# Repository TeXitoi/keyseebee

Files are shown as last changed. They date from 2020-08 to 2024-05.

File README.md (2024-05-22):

# KeySeeBee

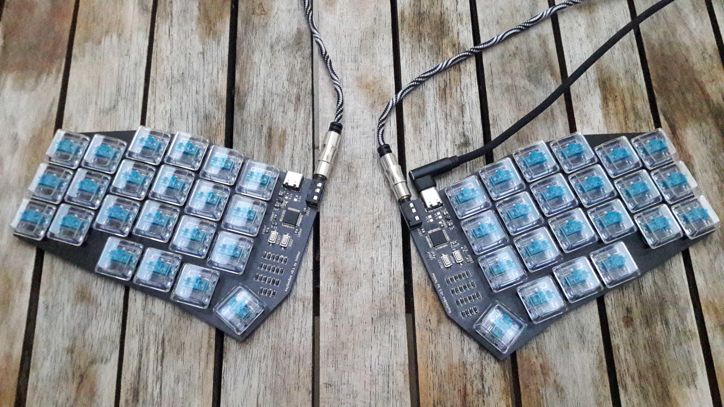
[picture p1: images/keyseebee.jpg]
KeySeeBee


KeySeeBee is a split ergo keyboard. It is only 2 PCB (so the name)
with (almost) only SMD components on it. It's only a keyboard, no LED,
no display, nothing more than keys and USB.

The firmware is [Keyberon](https://github.com/TeXitoi/keyberon), a
pure rust firmware.

## Features

 * 44 keys, using Cherry MX or Kailh choc switches, only 1U keycaps.
 * USB-C connector on the 2 sides.
 * TRRS cable for connecting the 2 halves (for power and UART communication between the 2 halves).
 * 2 STM32F072 MCU, with hardware USB DFU bootloader and crystal less USB;
 * Only onboard SMD component (except for the switches and TRRS
   connector).
 * [Plate files](cad/) (optional).

## Inspiration

 * [Plaid](https://github.com/hsgw/plaid) for "show the components"
 * [GergoPlex](https://www.gboards.ca/product/gergoplex) for "just a keyboard" and "only a PCB with SMD components"
 * [Lily58](https://github.com/kata0510/Lily58) for the thumb cluster
 * [Kyria](https://blog.splitkb.com/blog/introducing-the-kyria) for
   "don't be affraid of pinky stagger"

## Gallery

### v0.1, build by TeXitoi

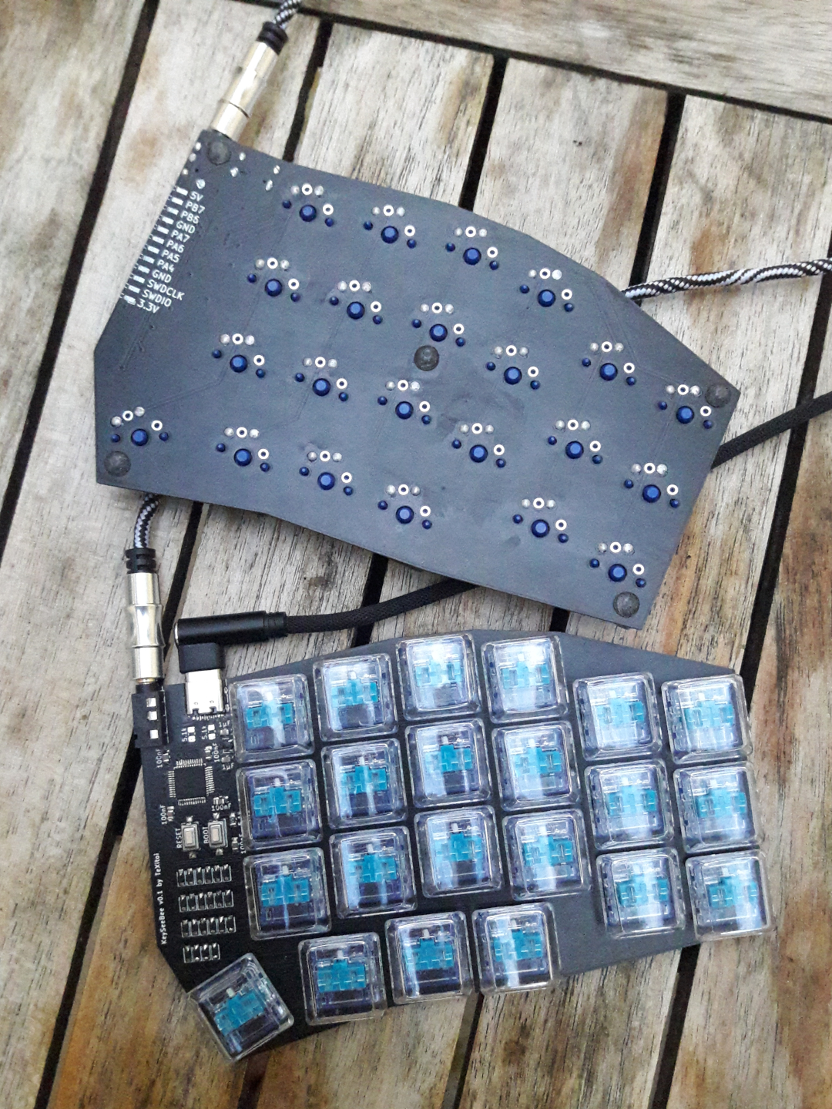
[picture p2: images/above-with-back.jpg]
From above with one side upside down


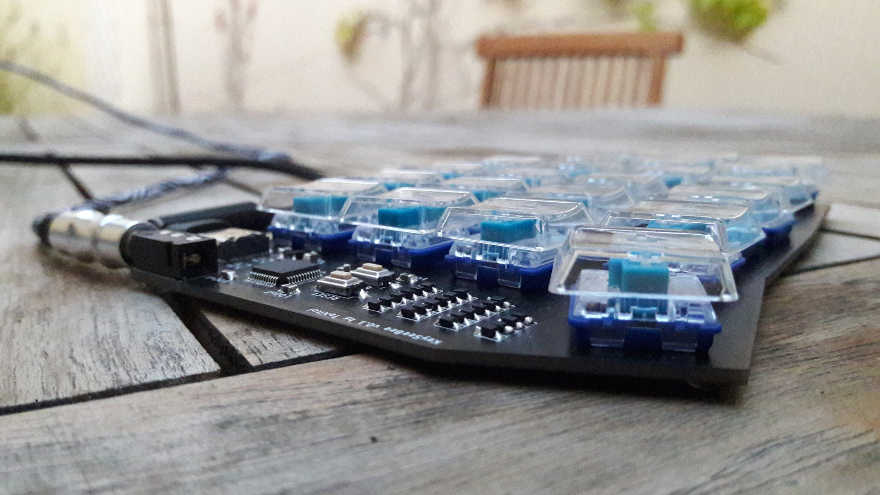
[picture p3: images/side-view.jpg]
Side view


### v0.1, build by TeXitoi, Gateron silent clear (MX footprint), 3D printed plate

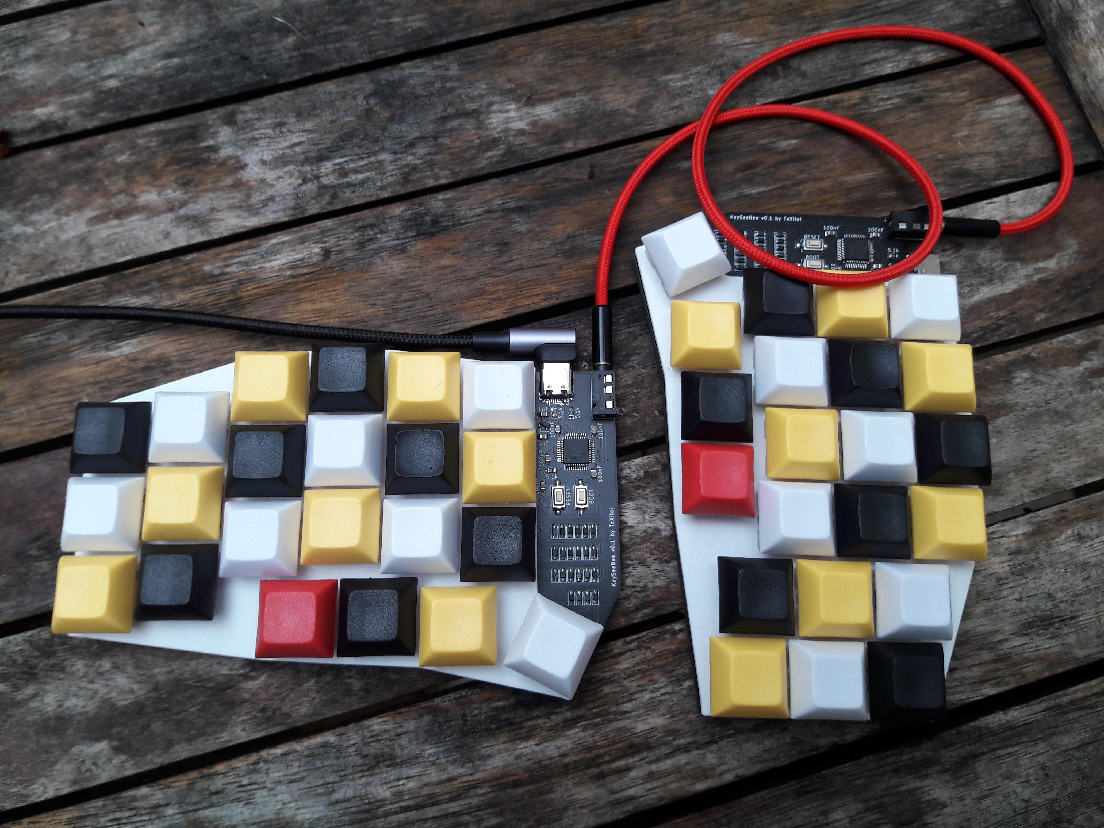
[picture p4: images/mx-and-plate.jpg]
From above


### v0.2, build by eropleco, with 1.2mm anodized aluminium plate

Left

Right

### v0.3, build by TeXitoi, Gateron silent clear, 3D printed fat plate

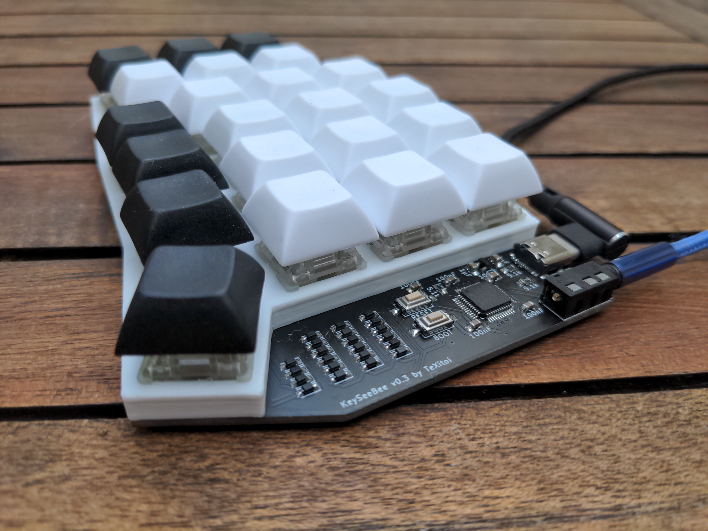
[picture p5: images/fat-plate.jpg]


## Bill Of Materials

Price is for 5 keyboards including shipping.

|Item |Package|Qty|Remarks |Price |
|---|---|--:|---|-----:|
|[Left PCB](pcb/gerbers/) | |  1|Ordered at [JLCPCB](https://jlcpcb.com)| |
|[Right PCB](pcb/gerbers/) | |  1|Ordered at [JLCPCB](https://jlcpcb.com)|33.14€|
|[USB-C connector](https://www.aliexpress.com/item/33004501788.html) |16 pins|  2| | 1.44€|
|[1N4148WS](https://www.aliexpress.com/item/32774043752.html) |SOD-323| 44|Price is for 1000 | 2.82€|
|[PJ320A TRRS connector](https://www.aliexpress.com/item/4000661212458.html)| |  2| | 1.01€|
|[STM32F072CBT6 MCU](https://www.aliexpress.com/item/1005002841528809.html)|LQFP-48|  2|STM32F072C8T6 would also work | 9.65€|
|[XC6206P332MR regulator](https://www.aliexpress.com/item/33015891307.html)|SOT-23 |  2|Price is for 50 | 1.93€|
|[SMD switch](https://www.aliexpress.com/item/4000546059630.html) | 3×6mm |  4|Price is for 100 | 1.35€|
|[5.1kΩ resistor](https://www.aliexpress.com/item/32865947306.html) | 0805  |  6|Price is for 100 | |
|[1µF capacitor](https://www.aliexpress.com/item/32964553793.html) | 0805  |  4|Price is for 100 | |
|[100nF capacitor](https://www.aliexpress.com/item/32964553793.html) | 0805  | 10|Price is for 100 | 3.46€|
|[Bumpers](https://www.aliexpress.com/item/32289191938.html) | 5×2mm | 10|Price is for 100 | 1.75€|
|[Cherry MX compatible](https://www.aliexpress.com/item/32836368723.html) or [Kailh Choc](https://www.aliexpress.com/item/1005005883472162.html) switch|5 pins (PCB mount)|44| | |
|1U keycap compatible with the chosen switches | | 44| | |
|[TRRS cable](https://www.aliexpress.com/item/1005003677396291.html) |Jack 3.5mm| 1|4 contacts needed | |
|[USB-C cable](https://www.aliexpress.com/item/1005002811739151.html) | |  1|USB-2 is enough | |

About 60€ without switches, keycaps and cables for 5 keyboards
(12€/keyboard).

## Compiling and flashing

Install the complete toolchain and utils:

```shell
curl https://sh.rustup.rs -sSf | sh
rustup target add thumbv6m-none-eabi
rustup component add llvm-tools-preview
cargo install cargo-binutils
sudo apt-get install dfu-util
```

Compile:

```shell
cd firmware
cargo objcopy --bin keyseebee --release -- -O binary keyseebee.bin
```

To flash using dfu-util, launch it with:
```shell
dfu-util -w -d 0483:df11 -a 0 -s 0x08000000:leave -D keyseebee.bin
```
Then, put the board in dfu mode by pressing BOOT, pressing and releasing
RESET and releasing BOOT. The upload should began as soon as the
computer detect the board in dfu mode.

The first time, if the write fail, your flash might be protected. To
unprotect:

```shell
dfu-util -d 0483:df11 -a 0 -s 0x08000000:force:unprotect -D keyseebee.bin
```

Ideally both sides needs to be flashed, but for changes that only affect the layout it's strictly not needed as the side connected with the USB cable will determine the layout. In fact, you can have different layouts stored on each half, meaning you can switch back and forth between two layouts by moving the USB cable between the two halves.

## What's the layout

Here is the [empty keyboard-layout-editor](http://www.keyboard-layout-editor.com/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) describing the layout.

I use the [ergol layout](https://ergol.org), so this is [the main layer](http://www.keyboard-layout-editor.com/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'%3B&@_y:-0.875&x:5%3B&=%0A%0A%0A%25%0A%0A%0AW&_x:5%3B&=%0A%0A%0A%2F@%0A%0A%0AJ%3B&@_y:-0.625&x:1%3B&=%0A%0A%C3%A2%0A%5E%0A%0A%0AQ&_x:13%3B&=%0A%0A%C3%BB%0A%60%0A%0A%0AY%3B&@_y:-0.8500000000000001&a:6%3B&=Tab&_x:15&a:4&f:3%3B&=%7B%0A%5B%3B&@_y:-0.7999999999999998&x:3&f:4%3B&=%0A%0A%C3%A8%0A%29%0A%0A%0AE&_x:9%3B&=%0A%0A%C3%AE%0A-%0A%0A%0AT%3B&@_y:-0.8500000000000001&x:2%3B&=%0A%0A%C3%A9%0A%28%0A%0A%0AS&_x:1%3B&=%0A%0A%C3%AA%0A%7D%0A%0A%0AN&_x:7%3B&=%0A%0A%29%0A+%0A%0A%0AR&_x:1%3B&=%0A%0A%C3%AF%0A%2F%2F%0A%0A%0AI%3B&@_y:-0.875&x:5%3B&=%0A%0A%C3%B1%0A%2F=%0A%0A%0AF&_x:5%3B&=%0A%0A%28%0A%5C%0A%0A%0AL%3B&@_y:-0.625&x:1%3B&=%0A%0A%C3%A0%0A%7B%0A%0A%0AA&_x:13%3B&=%0A%0A%C3%B9%0A%22%0A%0A%0AU%3B&@_y:-0.8500000000000001%3B&=%7D%0A%5D&_x:15&f:3%3B&=%22%0A'%3B&@_y:-0.7999999999999998&x:3&f:4%3B&=%3F%0A-%0A%E2%80%91%0A%5D&_x:9%3B&=%0A%0A%CE%B1%0A%2F%3B%0A%0A%0AG%3B&@_y:-0.8500000000000001&x:2%3B&=%0A%0A%C3%9F%0A%5B%0A%0A%0AX&_x:1%3B&=%0A%0A%E2%80%93%0A%2F_%0A%0A%0AV&_x:7%3B&=%0A%0A%0A!%0A%0A%0AH&_x:1%3B&=%2F%3B%0A,%0A%C2%B7%0A%2F:%3B&@_y:-0.875&x:5%3B&=%0A%0A%E2%80%94%0A%23%0A%0A%0AB&_x:5%3B&=%2F:%0A.%0A%E2%80%A6%0A%7C%3B&@_y:-0.625&x:1%3B&=%0A%0A%C3%A6%0A~%0A%0A%0AZ&_x:13%3B&=%0A%0A%C5%AD%0A%3F%0A%0A%0AK%3B&@_y:-0.8500000000000001%3B&=+%0A%2F=&_x:15&f:3%3B&=%7C%0A%5C%3B&@_y:-0.6500000000000004&x:2.5&a:6&f:4%3B&=GUI&_x:10%3B&=%E2%87%A7%20+%20AltGr%3B&@_rx:4&ry:8.175&y:-4.675000000000001&x:-0.5%3B&=Alt%3B&@_y:-0.875&x:0.5&a:0%3B&=nbsp%0A%E2%90%A3%0A%E2%80%99%0A%E2%90%A3%0Alayer%201%3B&@_rx:13&y:-4.675000000000001&x:-0.5&a:6%3B&=AltGr%3B&@_y:-0.875&x:-1.5&a:7%3B&=Layer%202%3B&@_r:30&rx:4&y:-4.825000000000001&x:-0.5&a:6&f:3%3B&=Ctrl%3B&@_r:-30&rx:13&y:-4.825000000000001&x:-0.5%3B&=%E2%87%A7) when I type.

The [layer 1](http://www.keyboard-layout-editor.com/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) is activated by holding `space`.

The [layer 2](http://www.keyboard-layout-editor.com/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,&_x:7%3B&=+&_x:1%3B&=%2F%2F%3B&@_y:-0.875&x:5%3B&=%2F=&_x:5%3B&=.%3B&@_y:-0.625&x:1%3B&=&_x:13%3B&=*%3B&@_y:-0.8500000000000001%3B&=&_x:15&f:3%3B&=%3B&@_y:-0.6499999999999999&x:2.5&a:6&f:4%3B&=GUI&_x:10&a:7%3B&=%3B&@_rx:4&ry:8.175&y:-4.675&x:-0.5&a:6%3B&=Alt%3B&@_y:-0.875&x:0.5&a:7%3B&=Ctrl+%E2%90%A3%3B&@_rx:13&y:-4.675&x:-0.5%3B&=AltGr%3B&@_y:-0.875&x:-1.5&g:true%3B&=%3B&@_r:30&rx:4&y:-4.825&x:-0.5&g:false&a:6&f:3%3B&=Ctrl%3B&@_r:-30&rx:13&y:-4.825&x:-0.5%3B&=%E2%87%A7) is activated by holding `Layer 2`.

The [layer 3](http://www.keyboard-layout-editor.com/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)
is activaded by holding `space` then `Layer 2`.

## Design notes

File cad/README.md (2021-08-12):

# Plate files

In version v0.1 and v0.2, the right thumb cluster is not at the exact
same place as the left one. It is corrected in v0.3 and after. If you
need a plate for pre-v0.3, look at the `is_right` option in the code.

You can find here some plates for the keyboard:
 * svg are seen from the top
 * stl are seen from the bottom, to have the visible side on the bed of a 3D printer.
 
The scad file is the source of these files. You can tune it to change,
for example, the swich hole size, depending on the tolerance you need.

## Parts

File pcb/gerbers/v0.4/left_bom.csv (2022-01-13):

Comment | Designator | Footprint | LCSC
100nF | C1,C2,C3,C4,C5 | Capacitor_SMD:C_0805_2012Metric_Pad1.15x1.40mm_HandSolder | C49678
1µF | C6,C7 | Capacitor_SMD:C_0805_2012Metric_Pad1.15x1.40mm_HandSolder | C28323
1N4148WS | D5,D6,D7,D9,D10,D11,D12,D14,D15,D16,D17,D19,D20,D21,D23,D24,D25,D26,D33,D34,D35,D36 | Diode_SMD:D_SOD-323_HandSoldering | C2128
USB_C_Receptacle_USB2.0 | J1 | kicad-usb:USB_C_Receptacle_HRO_TYPE-C-31-M-12 | C136423
AudioJack4 | J2 | keebio:TRRS-PJ-320A-no-Fmask
Conn_01x12_Male | J3 | kicad-harwin:Harwin_M20-89012xx_1x12_P2.54mm_Horizontal
5.1k | R1,R6,R7 | Resistor_SMD:R_0805_2012Metric_Pad1.15x1.40mm_HandSolder | C27834
BOOT | SW1 | Button_Switch_SMD:SW_SPST_CK_RS282G05A3 | C720381
RESET | SW2 | Button_Switch_SMD:SW_SPST_CK_RS282G05A3 | C720381
SW_Push | SW3,SW4,SW5,SW7,SW8,SW9,SW10,SW12,SW13,SW14,SW15,SW17,SW18,SW19,SW21,SW22,SW23,SW24,SW31,SW32,SW33,SW34 | custom:CherryMX_Choc_1u
STM32 | U1 | Package_QFP:LQFP-48_7x7mm_P0.5mm | C80488
LDO | U2 | Package_TO_SOT_SMD:SOT-23 | C5446

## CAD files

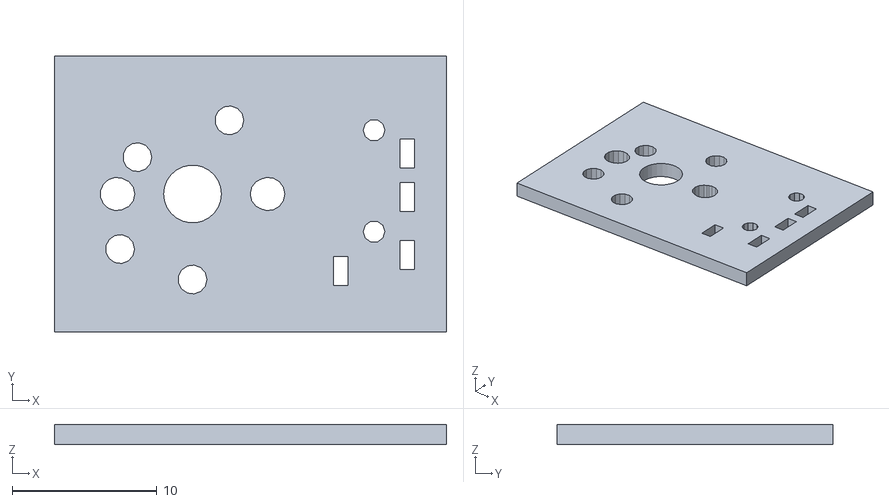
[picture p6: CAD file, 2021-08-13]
cad/cutting_pattern.stl
27.0 x 19.0 x 1.40

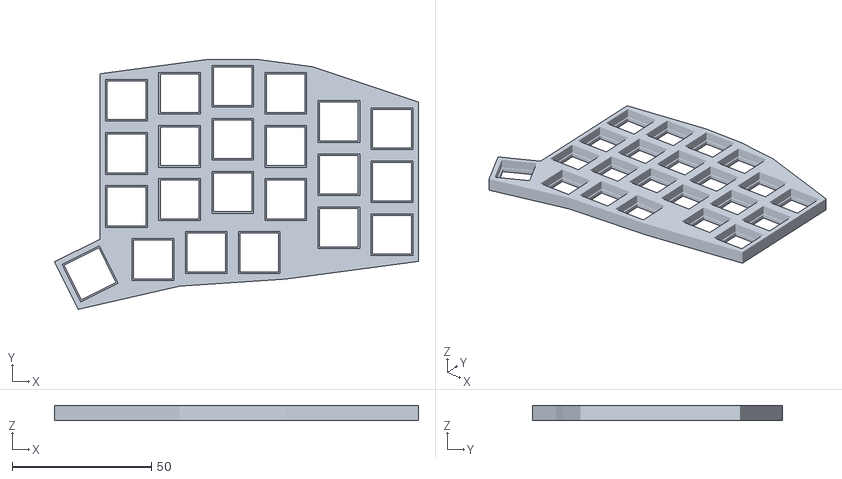
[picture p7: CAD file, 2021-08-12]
cad/fat_mx_plate.stl
130.6 x 89.6 x 5.40

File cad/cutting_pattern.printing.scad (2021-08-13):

$fs=0.5;
$fa=1;
in=25.4;
g=0.05*in;
e=0.5;// added diameter to switch holes

linear_extrude(1.4) {
     difference() {
          union() {
               square(19.05, center=true);
               translate([19.05/2+3, 0]) square([10, 19.05], center=true);
          }

          // MX
          circle(d=0.157*in);
          translate([2*g, 4*g]) circle(d=0.059*in+e);
          translate([-3*g, 2*g]) circle(d=0.059*in+e);
          translate([-4*g, 0]) circle(d=0.067*in+e);
          translate([4*g, 0]) circle(d=0.067*in+e);

          // Choc
          circle(d=3.2);
          translate([0, -5.9]) circle(d=0.059*in+e);
          translate([-5, -3.8]) circle(d=0.059*in+e);
          translate([-5.22, 0]) circle(d=1.8+e);
          translate([5.22, 0]) circle(d=1.8+e);

          // PJ320A
          translate([19.05/2+3, 6]) {
               translate([0, -1.6]) circle(d=1.5);
               translate([0, -8.6]) circle(d=1.5);

               for (i=[-3.2, -6.2, -10.2]) translate([2.3, i]) square([1,2], center=true);
               translate([-2.3, -11.3]) square([1,2], center=true);
          }
     }
}

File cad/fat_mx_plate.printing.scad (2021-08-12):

use <functions.scad>

difference() {
     linear_extrude(5.4) plate();
     translate([0,0,1.6]) linear_extrude(5.4) key_placement() square(15, center=true);
}

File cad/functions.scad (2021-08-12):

// You can change the parameters in the header in openscad, then
// render, and then export in the format you need.
//
// You can also include this file in your own scad file, and use the
// modules to create your own case:
//  - outline module (2D outline of the plate),
//  - plate module (2D draw of the plate, with switch holes),
//  - key_placement module (2D placement of the keys centered, to be
//    used with children) to create your own case.

switch_hole=13.9;// by spec should be 14, can be adjusted for printer imprecision

// Code here, not to be modified if you want keyseebee compatibility
inter_switch=19.05;
d=2.54;
delta=[-d,0,d,0,-4*d,-5*d];// column stagger

// this is a bug in v0.1 and v0.2, not needed after
right_thumb_offset=0.635;
function thumb_offset(is_right) = (is_right?1:0)*right_thumb_offset;

module key_placement_without_extreme(is_right=false) {
     for (i=[0:5]) for (j=[0:2]) translate([(i-1)*inter_switch, -(j-1)*inter_switch+delta[i]]) children();
     for (i=[0:2]) translate([(i-0.5)*inter_switch+thumb_offset(is_right), -2*inter_switch+min(delta[i], delta[i+1])]) children();
}

module extreme_key_placement(is_right=false) {
     translate([-32.131+thumb_offset(is_right), -45.720]) rotate(26.5) children();
}

module key_placement(is_right=false) {
     key_placement_without_extreme(is_right) children();
     extreme_key_placement(is_right) children();
}

module outline(is_right=false) {
     union() {
          hull() key_placement_without_extreme(is_right) square(inter_switch, center=true);
          translate([-inter_switch, -2*inter_switch+delta[0]]) square(inter_switch, center=true);
          hull() {
               extreme_key_placement(is_right) square(inter_switch, center=true);
               translate([-0.5*inter_switch+thumb_offset(is_right), -2*inter_switch+delta[0]]) square(inter_switch, center=true);
          }
     }
}

module plate(is_right=false) {
     difference() {
          outline(is_right);
          key_placement(is_right) square([switch_hole, switch_hole], center=true);
     }
}

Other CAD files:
cad/plate.2d.scad
cad/plate.scad

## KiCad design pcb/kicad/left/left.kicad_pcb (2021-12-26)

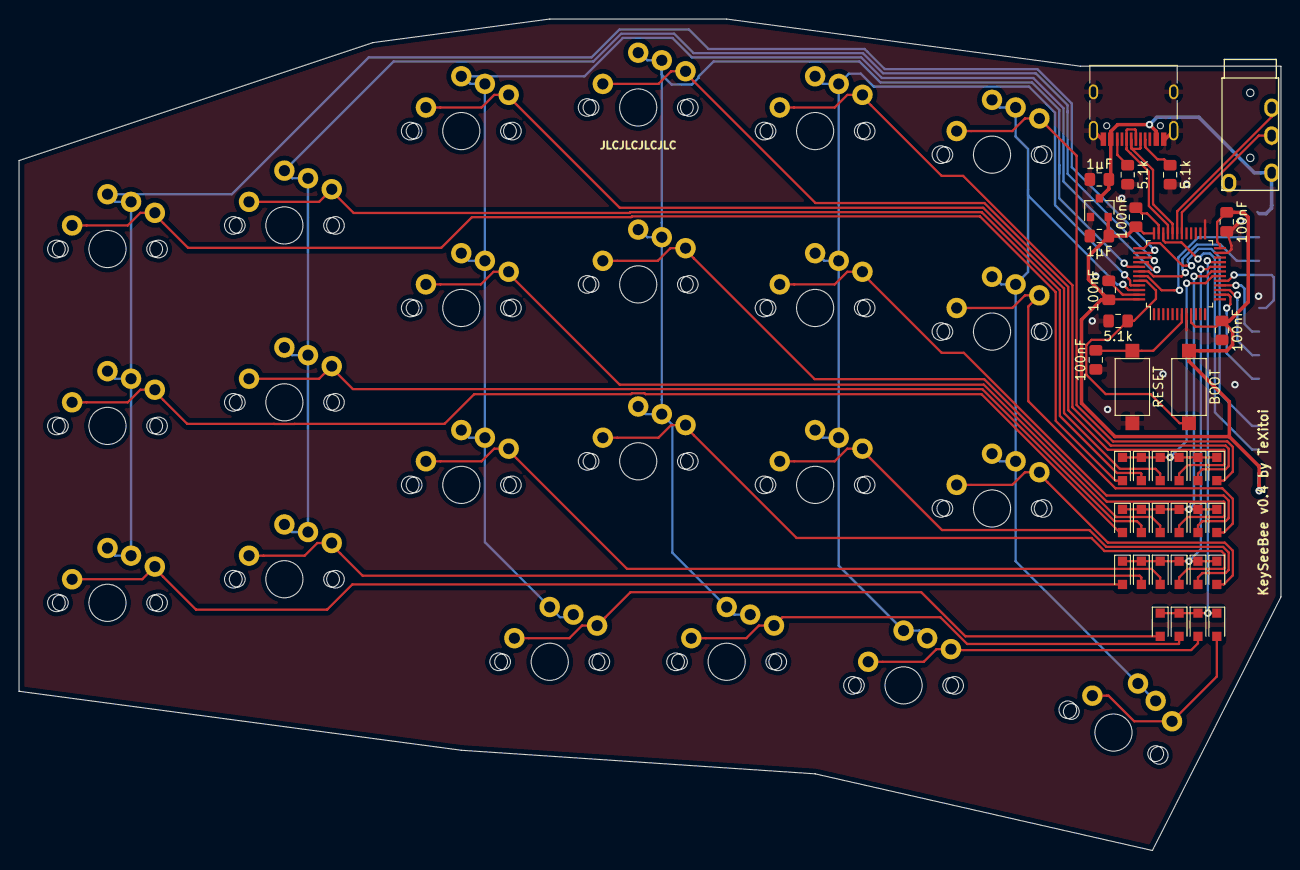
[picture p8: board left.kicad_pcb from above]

Board: 2 copper layers, 135.9 x 89.5 mm, 61 parts (1 on the bottom side), 51 nets.

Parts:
C1, C2, C3, C4, C5: 100nF; C_0805_2012Metric_Pad1.15x1.40mm_HandSolder
C6, C7: 1µF; C_0805_2012Metric_Pad1.15x1.40mm_HandSolder
D5, D6, D7, D9, D10, D11, D12, D14, D15, D16, D17, D19, D20, D21, D23, D24, D25, D26, D33, D34, D35, D36: 1N4148WS; D_SOD-323_HandSoldering
J1: USB_C_Receptacle_USB2.0; USB_C_Receptacle_HRO_TYPE-C-31-M-12
J2: AudioJack4; TRRS-PJ-320A-no-Fmask
J3: Conn_01x12_Male; Harwin_M20-89012xx_1x12_P2.54mm_Horizontal
R1, R6, R7: 5.1k; R_0805_2012Metric_Pad1.15x1.40mm_HandSolder
SW1: BOOT; SW_SPST_CK_RS282G05A3
SW2: RESET; SW_SPST_CK_RS282G05A3
SW3, SW4, SW5, SW7, SW8, SW9, SW10, SW12, SW13, SW14, SW15, SW17, SW18, SW19, SW21, SW22, SW23, SW24, SW31, SW32, SW33, SW34: SW_Push; CherryMX_Choc_1u
U1: STM32; LQFP-48_7x7mm_P0.5mm
U2: LDO; SOT-23

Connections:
3.3V: C2.2, C3.2, C4.2, C5.2, C6.2, J3.1, SW1.2, U1.9, U1.24, U1.36, U1.48, U2.2
5V: C7.2, J1.A4, J1.A9, J1.B4, J1.B9, J2.2, J3.12, U2.3
COL1: SW3.2, SW4.2, SW5.2, U1.38
COL2: SW17.2, SW18.2, SW19.2, U1.39
COL3: SW7.2, SW8.2, SW9.2, SW10.2, U1.40
COL4: SW21.2, SW22.2, SW23.2, SW24.2, U1.41
COL5: SW31.2, SW32.2, SW33.2, SW34.2, U1.45
COL6: SW12.2, SW13.2, SW14.2, SW15.2, U1.46
D+: J1.A6, J1.B6, U1.33
D-: J1.A7, J1.B7, U1.32
GND: C1.1, C2.1, C3.1, C4.1, C5.1, C6.1, C7.1, J1.A1, J1.A12, J1.B1, J1.B12, J1.S1, J2.1, J3.4, J3.9, R1.2, R6.2, R7.2, SW2.1, U1.8, U1.23, U1.25, U1.35, U1.47, U2.1
unnamed: C1.2, SW2.2, U1.7
unnamed: D5.2, SW3.1
unnamed: D6.2, SW4.1
unnamed: D7.2, SW5.1
unnamed: D9.2, SW7.1
unnamed: D10.2, SW8.1
unnamed: D11.2, SW9.1
unnamed: D12.2, SW10.1
unnamed: D14.2, SW12.1
unnamed: D15.2, SW13.1
unnamed: D16.2, SW14.1
unnamed: D17.2, SW15.1
unnamed: D19.2, SW17.1
unnamed: D20.2, SW18.1
unnamed: D21.2, SW19.1
unnamed: D23.2, SW21.1
unnamed: D24.2, SW22.1
unnamed: D25.2, SW23.1
unnamed: D26.2, SW24.1
unnamed: D33.2, SW31.1
unnamed: D34.2, SW32.1
unnamed: D35.2, SW33.1
unnamed: D36.2, SW34.1
unnamed: J1.A5, R7.1
unnamed: J1.B5, R6.1
unnamed: R1.1, SW1.1, U1.44
PA4: J3.5, U1.14
PA5: J3.6, U1.15
PA6: J3.7, U1.16
PA7: J3.8, U1.17
PB6: J3.10, U1.42
PB7: J3.11, U1.43
ROW1: D5.1, D9.1, D14.1, D19.1, D23.1, D33.1, U1.18
ROW2: D6.1, D10.1, D15.1, D20.1, D24.1, D34.1, U1.19
ROW3: D7.1, D11.1, D16.1, D21.1, D25.1, D35.1, U1.20
ROW4: D12.1, D17.1, D26.1, D36.1, U1.21
RX: J2.4, U1.31
SWDCLK: J3.3, U1.37
SWDIO: J3.2, U1.34
TX: J2.3, U1.30

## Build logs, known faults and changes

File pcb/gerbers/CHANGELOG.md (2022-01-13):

# Gerber change log

## v0.4 (TBD)

Manufactured SMT.

Not finished, not manufactured, not tested.

## v0.3 (2020-12-03)

Minor modifications for an exact symetry of the key placements.

Modifications:
 * Change the right thumb cluster placement to be exactly as the left
   one.
 * Change a bit the cutout to be (almost) exactly around the extreme
   thumb key.

Tested by TeXitoi, fully functionnal.

## v0.2 (2020-09-05)

Same as v0.1 with some bugs fixed.

Modifications:
 * Fix LDO.
 * Fix Diodes.
 * Remove references of the MCU and the USB connector on the left to
   be consistent with the right.

Tested by eropleco, fully functionnal.

Bugs:
 * The right thumb cluster is a bit offset comparing to the left one.

## v0.1 (2020-08-02)

First version. Ordered at JLCPCB. Tested and functional with the
workaround.

This version has the placeholder `JLCJLCJLCJLC` for use with the
option "Remove Order Number -> Specify a location" at JLCPCB.

Bugs:
 * LDO is badly wired. Workaround: solder it with a roation of 120°
   clockwise.
 * Diodes are in the wrong direction. Workaround: solder them in
   reverse (line on the diode up).
 * The right thumb cluster is a bit offset comparing to the left one.

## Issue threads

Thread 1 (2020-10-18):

Plate files in DFX format

octol, 2020-10-18:
I'd be quite interested in trying metal switch plates on my KeyBeeSee. Something that still exposed the components in the middle would be preferable. If we had DXF files available this would make it easy for users to have plates cut

TeXitoi, 2020-10-20:
It would also be great to have SVG to be presented in https://github.com/jhelvy/splitKbCompare

I'll try to do a scad when I have a bit of time, and 3D print it to be sure that's the good size.

eropleco, 2020-10-30:
Having plates would be quite nice indeed, and I think making the plates as another set of PCBs might work too, since it'd be a very economical solution compared to getting a metal plate cut.

TeXitoi, 2020-10-30:
Well, the main concept is minimalism, only a PCB. There is nothing in the PCB to support any plate.

octol, 2020-10-30:
Correct me if I'm wrong by I think what was meant was to have FR4 plates, which would be a lot cheaper to produce. Not to use a PCB as plate?

octol, 2020-10-30:
I too would actually prefer to have an FR4 plate, too keep the black theme I've got going on mine currently

TeXitoi, 2020-10-30:
Yeah, I mean the PCB doesn't help in using a okate, you'll need a floating PCB, and a wide plate to connect with a bottom plate. You can't have any screw on the PCB.

octol, 2020-10-30:
I was just thinking of a floating plate, only attached to the switches. This is what I have now on my ErgoTravel and it works great. Gives extra rigidity without making the board any taller

octol, 2020-10-30:
So the plate would have the exact same outer dimensions as the pcb, except for the inner area where all the components are, which I think should be left open as I like the exposed components esthetics

TeXitoi, 2020-10-30:
That's who I would do the design, using openscad.

TeXitoi, 2020-11-03:
https://github.com/TeXitoi/keyseebee/tree/master/cad

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

Note that the left and the right plate are not exactly the same, there is a small offset of the right cluster. To be corrected in v0.3

TeXitoi, 2020-11-03:
I'll close this when keyseebee is on https://github.com/jhelvy/splitKbCompare

TeXitoi, 2020-11-03:
https://github.com/jhelvy/splitKbCompare/issues/28

TeXitoi, 2020-11-03:
You can export in DXF using openscad. You can also change the switch hole size to match the tolerance you need.

For ordering FR4 plates, I suppose you need to construct a gerber from the file, using the svg as the cut layer. You may add some copper zone, and can do some crazy art using the different layers. https://wiki.ai03.com/books/pcb-design/page/pcb-guide-part-6---fill-zones-decoration-and-production You may have extra fees because of complicated cuts.

eropleco, 2020-11-06:
> Yeah, I mean the PCB doesn't help in using a plate, you'll need a floating PCB, and a wide plate to connect with a bottom plate. You can't have any screw on the PCB.

Thank you for making the plate files! And yes, this has always been my intention, to just have a floating plate to keep the switches in place, mostly for easy cap removal.

TeXitoi, 2020-11-06:
@eropleco How does a plate help for cap removal? That's not a hotswap board.

And, out of curiosity, do you have a keyseebee? Maybe you sourced the PCB yourself?

octol, 2020-11-06:
Removing the MBK keycaps on mine you have to be very very careful to not rip the solder joints as the caps sits very firmly on the switches. A plate might help here?

Sort of related, I noticed that on my Ferris I don't have that problem since the switch alignment holes are slightly slightly smaller making the switches sit firmly anchored on the pcb, even without them being soldered. Not sure if it's because of production tolerances the holes were designed to be smaller?

TeXitoi, 2020-11-06:
Did you removed a switch while trying to remove a keycap? If yes, where the join break? Maybe you don't put enough solder?

The ferris is a choc only board. KeySeeBee is also MX compatible, and the plastic legs are not exactly the same, thus there is 2 holes for each lateral plastic legs that are a bit offset. You then have a less strong press fit.

octol, 2020-11-06:
By pulling carefully while wiggling the keycap puller I managed to remove the keycaps without removing any switches

Since the solder joints are only on one side, pulling the keycaps straight up means the switch will break away from the pcb on the other non-soldered side, a bit like opening a hinge. So the amount of solder has no real effect there

Didn't know the alignment holes for MX and Choc were slightly different, and yeah looking closer I see what you mean

TeXitoi, 2020-11-06:
OK, I see what you mean. The transparent keycaps are not so hard to remove, so I have no problem removing them. Maybe a plate can help then.

eropleco, 2020-11-06:
> And, out of curiosity, do you have a keyseebee? Maybe you sourced the PCB yourself?

I just built one recently but haven't yet finished soldering the switches since the plate is now a thing. I'll post some images eventually when I'm done with it.

> How does a plate help for cap removal? That's not a hotswap board.

The key caps on the choc switches are very difficult to remove for me without exerting a huge amount of force on the legs, and a plate will help with this problem by holding the switches in place. I will need to make some changes to the design so the choc switches actually clicks into the plate though.

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

TeXitoi, 2020-11-06:
@eropleco So you sourced yourself a v0.2? Can I validate that everything is functional on the gerber page?

The place should match the choc keycaps, what you mean by "make some changes to the design so the choc switches actually clicks into the plate"? You can change easily the different values, as switch holes and (for the stl) plate thinkness by editing the parameters at the top of the plate.scad file.

eropleco, 2020-11-06:
Yes, I used v0.2 when ordering the PCB. I was about to post an issue here to tell you about it but since I haven't actually finished the board, I thought I'd hold that off for a bit before I can verify everything. So far what I *can* confirm is that all of the footprints are correct, I can flash the firmware, and the keyboard does send keycodes to the computer. I didn't test *all* of the keys, nor have I tested UART communication yet due to the lack of a usable TRRS audio cable.

About the modifications, I need to change the thickness of the plate, and the size of the opening. According to the illustration in the middle, the thickness is 1.3mm, so the standard 1.2mm PCB thickness should work quite well here. The opening should be 13.8mm.

I'm not familiar with openscad, I see I can change both of these parameters in the scad source file, but how do I get the left side of the plate?

TeXitoi, 2020-11-06:
I added comments in the scad file, tell me if that's enough to tune for a non openscad user.

eropleco, 2020-11-06:
Thank you, the comments are very helpful. I'll share some pictures when I get my plates manufactured.

TeXitoi, 2020-11-06:
For the holes, by the datasheet, they must be between 13.8 and 14.5. Generally, you add a bit of tolerance, so 14mm is a standard choice.

eropleco, 2020-11-06:
I measured the switch with a digital caliper and got 13.8mm too, so that's what I'm inclined to use. The actual body of the switch is 13.6mm wide, the 13.8mm measurement includes these several tiny lips. 14mm is dangerously close to the width of the 4 clips, which measures just 14.3mm here.
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

TeXitoi, 2020-11-06:
OK, I'd be interested in feedbacks on the plate one time you've done and tested it @eropleco.

eropleco, 2020-11-19:
@TeXitoi This is is the end result. My soldering job weren't perfect but I tried (notice the slightly crooked diodes). The plate is 1.2mm anodized aluminium, and I used 13.9mm for the hole diameter. The manufacturing precision wasn't great so a couple of holes were a bit loose, and there was one that is a bit too tight, so I had to shave the switch down a tiny bit. Overall it's not too bad though, I'm pretty happy about how it turned out in the end.

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

TeXitoi, 2020-11-19:
Ho, really great! Out of curiosity, how much the plates did cost?

TeXitoi, 2020-11-19:
Can I use the photos in the readme?

eropleco, 2020-11-19:
The plates cost me about $20 in total at a local shop, and yes, you can use the images in the readme :)

TeXitoi, 2020-11-19:
I've updated the README.md and the pcb/gerbers/CHANGELOG.md accordingly. Thanks.

$20 is not so expensive, would think anodized aluminium to be more expensive. It looks great!

And your soldering job is really great! Much better than mine!

TeXitoi, 2020-11-19:
@eropleco I'm sure https://www.reddit.com/r/ErgoMechKeyboards/ would appreciate a photo of your build!

TeXitoi, 2020-11-19:
@eropleco also, what did you do for homing? I can see a dot in the keycap.

eropleco, 2020-11-19:
Thanks for the compliment, I was being extra slow and careful while making this so it'd look neat. Washed the board a couple of times before putting on the switches, too.

Regarding that dot, since I wasn't able to source any existing key caps with a bump on it, I just poked a hole on the cap with a heated straight pin, clipped the head off with about 0.5mm of the stem left, and gently pushed that bit in while heating it with a soldering iron. This way I'd be left with a round metal bump that is semi-embedded within the plastic. A friend suggested epoxy, but my two component epoxy has expired, and tbh I'm not sure how would I be able to shape a tall, uniform bump with it, so I didn't try that idea. A small SMT part that doesn't have solder exposed on top would probably work too, such as a crystal.

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

TeXitoi, 2020-11-20:
keyseebee is now live on https://jhelvy.shinyapps.io/splitkbcompare/

Closed 2020-11-20.

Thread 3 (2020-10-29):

Clarify documentation about flashing

octol, 2020-10-29:
Building the firmware and flashing the board was pretty straightforward, however something that would be nice to clarify in the documentation is if it's necessary to flash both sides (is it? I've not done it and I have not noticed any issues?).
Also is my assumption correct in that you can use either side as primary?

(Sometimes I think issues/questions like these better belong in a forum, alternatively Discord. For example I'd be happy to raise a PR if I knew the answer to the above.)

TeXitoi, 2020-10-29:
if you only change the layout, you can only flash the side you plug. You can have 2 different layout on each side, and plugging in one side will use the layout on this side.

Basically, each side send coords of press and release of each key (after debouncing) via the TRRS cable and also to the layout manager. So the layout manager receive key event via another task on the same microcontroller and via UART on the TRRS cable.

Then, the layout send to USB the events if USB is connected.

TeXitoi, 2020-10-29:
If you want a chat, I'm present on a few embedded rust chan on matrix.org. I will not go to discord because that's closed, and I don't want to multiply networks I connect. (Also, there is a matrix client on my ungoogled smartphone, and that's not the case for the other protocols)

TeXitoi, 2020-10-29:
In theory, you can plug each side to a given computer, and you'll type on the 2 computers at the same time. But I affraid to try it as it would connect the usb power of the 2 computers in parallel. In theory, this is OK, but I don't think it's a good idea.

octol, 2020-10-29:
Hey that's pretty cool! Sounds great for being to toggle back and forth between different layouts, for example now that I'm testing home row mods but still want to easily be able to switch back

eropleco, 2020-10-30:
> In theory, you can plug each side to a given computer, and you'll type on the 2 computers at the same time. But I affraid to try it as it would connect the usb power of the 2 computers in parallel. In theory, this is OK, but I don't think it's a good idea.

Regarding this idea, I think you can simply add a switch on one side to disconnect VCC, and then add an ADuM3201 for isolating the UART communication: https://www.analog.com/media/en/technical-documentation/data-sheets/ADUM3200_3201.pdf

Closed 2020-11-04.

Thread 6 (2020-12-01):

0.1 LDO fix

keyboard-magpie, 2020-12-01:
A friend and I have some 0.1 keyseebee PCBs we're building up- is it possible to see a hi res photo, or have a description of the fix needed? I can see in some photos the LDO is at an unusual angle.

TeXitoi, 2020-12-01:
The alone leg must be at 1 o'clock. More info here: https://github.com/TeXitoi/keyseebee/blob/master/pcb/gerbers/CHANGELOG.md#v01-2020-08-02

Why did you printed the v0.1 and not v0.2?

keyboard-magpie, 2020-12-01:
Got it! :D Multimeter and such.
No idea why  did, i think he downloaded just before 0.2 was released.
Up and running now though.

https://cdn.discordapp.com/attachments/760085292048187442/783447743632244796/image0.jpg

TeXitoi, 2020-12-01:
Exactly. I hope you've soldered the diodes in the good direction. If not, that should be fixable in the firmware.

keyboard-magpie, 2020-12-01:
Oh, hadn't spotted that one! Presume they're opposite to silkscreen marking then?

TeXitoi, 2020-12-01:
yup, dash up.

keyboard-magpie, 2020-12-01:
Perfect thanks. Will pass this on.

TeXitoi, 2020-12-01:
yup, dash up.

Closed 2020-12-01.

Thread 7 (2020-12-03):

STM32F072CBT6 link expired in Readme.md

mejobloggs, 2020-12-03:
BOM section: https://github.com/TeXitoi/keyseebee/blob/master/README.md#bill-of-materials

Link for STM32F072CBT6 says product no longer exists.

Can you please update?

I would provide alternative link myself but I'm new to electronics and not sure if I will get the right product :)

STM32F072CBT6 seems scarce on AliExpress now?

TeXitoi, 2020-12-03:
Link updated. Thanks for letting me know.

If you build a KeySeeBee, please keep me informed!

Enjoy!

Closed 2020-12-03.

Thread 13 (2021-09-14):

How crazy would it be to try and incorporate a mouse into the PCB?

shaleh, 2021-09-14:
I like the idea of the chordie design, but I want the number of keys in keyseebee.

The trackball design there uses 6 wires.

TeXitoi, 2021-09-14:
You mean https://github.com/kbjunky/Chordie ?

There is a bunch of pads available on the backside. Should be enough for hacking something like that. You can see them on a photo on the readme.

TeXitoi, 2021-09-14:
Yeah, you have spi with cs on pa[4567] +gnd+ 3.3v on the back, exactly the pin you need for the trackball controller of the chordie. You'll need some code to create a rust driver of the trackball controller, and a bit of glue in keyseebee to manage the 2 devices.

shaleh, 2021-09-14:
Excellent. Thanks.

Closed 2021-09-15.

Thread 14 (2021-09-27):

IDEA: Collective order of presoldered kits

555wolfman, 2021-09-27:
This keyboard looks so slick! Well done!

I am interested in getting some kits, but i am afraid smd soldering is way beyond my skills.
As i know PCBway, JLCPCB and Elecrow offer assembly  services when ordering a PCB.

So my question is whether someone plans to order presoldered PCBs. I would like to join in.
And i am sure i am not the only one.

thanks in advance

Olaf

TeXitoi, 2021-09-27:
The files are not ready to send to a SMT assembly service, it lacks a proper BOM I suppose. Open to contribution about that.

Also, note that MCU are out of stock everywhere, so it will be difficult to find STM32F072 on the SMT assembly service, and ordering SMT without the MCU is quite useless, as it is one of the most difficult component to solver (with the USB connector).

TeXitoi, 2021-09-27:
If it becomes a thing, I can proxy for europe.

555wolfman, 2021-09-27:
thanks for offering that proxy service in case of a solution.

I have heard about that supply problem.

stm32f072c8t and f072cbt are available at aliexpress as well as atmega32u4 (which PCB companies can’t get either)

but i know that JLCPCB & co won’t order at aliexpress.
At least PCBway is willing to accept ordering parts by themselve as well as getting provided parts at the same time. But i can’t imagine how that kind of logistic stunt would work.

TeXitoi, 2021-09-27:
I think that's not a viable solution. On aliexpress, you sometime also have bad MCU. And the ones you find now are end of stock items, if you are lucky, and out of QA validation most of the time. And they are sold 5 times the official price if you are lucky. So nothing viable for a sane and affordable plan for now.

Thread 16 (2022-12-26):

why is PB12 connected to GND?

rukai, 2022-12-26:
I'm new to PCB design and have been using the keyseebee as a reference for my own board. (It will present itself as an HID keyboard and use rust)

I noticed that on the keyseebee stm32F072 pin 25 (PB12) is connected to ground while no other GPIO pins are.
Connecting to ground does allow the ERC to pass for that pin, so I can understand for that reason, but it still seems strange that only one of the pins would get that treatment.
So wanted to check if there was any deeper meaning to it other than "just is".

TeXitoi, 2022-12-26:
From my memory, that's the pin to detect the side: one is connected to ground, and on the other side, it's connected to 3.3V.

TeXitoi, 2022-12-26:
That's it: https://github.com/TeXitoi/keyseebee/blob/master/firmware/src/main.rs#L94-L95

rukai, 2022-12-26:
Ooooh thats a clever solution to that problem, thanks for taking the time to answer my question.

Closed 2022-12-26.

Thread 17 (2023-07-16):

diode-less vs matrix design

glehmann, 2023-07-16:
Probably just a dumb question, but the MCU seems to have enough pins for a diode-less design, so is there a reason I'm missing for choosing a matrix design instead of a diode-less design?

TeXitoi, 2023-11-20:
Yeah, maybe, I didn't think about diode less design at the time. It was before the sweep, so diode less was not so "mainstream" at the time.

Closed 2023-11-20.

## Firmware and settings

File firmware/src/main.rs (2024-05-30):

#![no_main]
#![no_std]

// set the panic handler
use panic_halt as _;

use core::convert::Infallible;
use core::mem::MaybeUninit;
use cortex_m::peripheral::SCB;
use embedded_hal::digital::v2::InputPin;
use hal::gpio::{gpiob, Floating, Input, Output, Pin, PullUp, PushPull};
use hal::prelude::*;
use hal::serial;
use hal::usb;
use hal::{stm32, timers};
use keyberon::debounce::Debouncer;
use keyberon::key_code::KbHidReport;
use keyberon::layout::{CustomEvent, Event, Layout};
use keyberon::matrix::Matrix;
use nb::block;
use rtic::app;
use stm32f0xx_hal as hal;
use usb_device::bus::UsbBusAllocator;
use usb_device::class::UsbClass as _;
use usb_device::device::UsbDeviceState;

mod layout;

type UsbClass = keyberon::Class<'static, usb::UsbBusType, ()>;
type UsbDevice = usb_device::device::UsbDevice<'static, usb::UsbBusType>;

#[link_section = ".uninit.GOTO_BOOTLOADER"]
static mut GOTO_BOOTLOADER: MaybeUninit<u8> = MaybeUninit::uninit();
const GO: u8 = 60;

#[cortex_m_rt::pre_init]
unsafe fn maybe_jump_bootloader() {
    let software_reset = (*hal::pac::RCC::ptr()).csr.read().sftrstf().bit_is_set();
    let jump_bootloader = software_reset && GOTO_BOOTLOADER.assume_init() == GO;
    GOTO_BOOTLOADER.write(0);
    if jump_bootloader {
        cortex_m::asm::bootload(0x1FFFC800 as _);
    }
}

pub fn bootloader() -> ! {
    unsafe { GOTO_BOOTLOADER.write(GO) };
    SCB::sys_reset()
}

trait ResultExt<T> {
    fn get(self) -> T;
}
impl<T> ResultExt<T> for Result<T, Infallible> {
    fn get(self) -> T {
        match self {
            Ok(v) => v,
            Err(e) => match e {},
        }
    }
}

#[app(device = crate::hal::pac, peripherals = true, dispatchers = [CEC_CAN])]
mod app {
    use super::*;

    #[shared]
    struct Shared {
        usb_dev: UsbDevice,
        usb_class: UsbClass,
        #[lock_free]
        layout: Layout<12, 4, 4, ()>,
    }

    #[local]
    struct Local {
        matrix: Matrix<Pin<Input<PullUp>>, Pin<Output<PushPull>>, 6, 4>,
        debouncer: Debouncer<[[bool; 6]; 4]>,
        timer: timers::Timer<stm32::TIM3>,
        transform: fn(Event) -> Event,
        tx: serial::Tx<hal::pac::USART1>,
        rx: serial::Rx<hal::pac::USART1>,
        buf: [u8; 4],
    }

    #[init(local = [bus: Option<UsbBusAllocator<usb::UsbBusType>> = None])]
    fn init(mut c: init::Context) -> (Shared, Local, init::Monotonics) {
        let mut rcc = c
            .device
            .RCC
            .configure()
            .hsi48()
            .enable_crs(c.device.CRS)
            .sysclk(48.mhz())
            .pclk(24.mhz())
            .freeze(&mut c.device.FLASH);

        let gpioa = c.device.GPIOA.split(&mut rcc);
        let gpiob = c.device.GPIOB.split(&mut rcc);

        let usb = usb::Peripheral {
            usb: c.device.USB,
            pin_dm: gpioa.pa11,
            pin_dp: gpioa.pa12,
        };
        *c.local.bus = Some(usb::UsbBusType::new(usb));
        let usb_bus = c.local.bus.as_ref().unwrap();

        let usb_class = keyberon::new_class(usb_bus, ());
        let usb_dev = keyberon::new_device(usb_bus);

        let mut timer = timers::Timer::tim3(c.device.TIM3, 1.khz(), &mut rcc);
        timer.listen(timers::Event::TimeOut);

        let pb12: &gpiob::PB12<Input<Floating>> = &gpiob.pb12;
        let is_left = pb12.is_low().get();
        let transform: fn(Event) -> Event = if is_left {
            |e| e
        } else {
            |e| e.transform(|i, j| (i, 11 - j))
        };

        let (pa9, pa10) = (gpioa.pa9, gpioa.pa10);
        let pins = cortex_m::interrupt::free(move |cs| {
            (pa9.into_alternate_af1(cs), pa10.into_alternate_af1(cs))
        });
        let mut serial = serial::Serial::usart1(c.device.USART1, pins, 38_400.bps(), &mut rcc);
        serial.listen(serial::Event::Rxne);
        let (tx, rx) = serial.split();

        let pa15 = gpioa.pa15;
        let matrix = cortex_m::interrupt::free(move |cs| {
            Matrix::new(
                [
                    pa15.into_pull_up_input(cs).downgrade(),
                    gpiob.pb3.into_pull_up_input(cs).downgrade(),
                    gpiob.pb4.into_pull_up_input(cs).downgrade(),
                    gpiob.pb5.into_pull_up_input(cs).downgrade(),
                    gpiob.pb8.into_pull_up_input(cs).downgrade(),
                    gpiob.pb9.into_pull_up_input(cs).downgrade(),
                ],
                [
                    gpiob.pb0.into_push_pull_output(cs).downgrade(),
                    gpiob.pb1.into_push_pull_output(cs).downgrade(),
                    gpiob.pb2.into_push_pull_output(cs).downgrade(),
                    gpiob.pb10.into_push_pull_output(cs).downgrade(),
                ],
            )
        });

        (
            Shared {
                usb_dev,
                usb_class,
                layout: Layout::new(&crate::layout::LAYERS),
            },
            Local {
                timer,
                debouncer: Debouncer::new([[false; 6]; 4], [[false; 6]; 4], 5),
                matrix: matrix.get(),
                transform,
                tx,
                rx,
                buf: [0; 4],
            },
            init::Monotonics(),
        )
    }

    #[task(binds = USART1, priority = 4, local = [rx, buf])]
    fn rx(c: rx::Context) {
        if let Ok(b) = c.local.rx.read() {
            c.local.buf.rotate_left(1);
            c.local.buf[3] = b;

            if c.local.buf[3] == b'\n' {
                if let Ok(event) = de(&c.local.buf[..]) {
                    handle_event::spawn(event).unwrap();
                }
            }
        }
    }

    #[task(binds = USB, priority = 3, shared = [usb_dev, usb_class])]
    fn usb_rx(c: usb_rx::Context) {
        (c.shared.usb_dev, c.shared.usb_class).lock(|usb_dev, usb_class| {
            if usb_dev.poll(&mut [usb_class]) {
                usb_class.poll();
            }
        });
    }

    #[task(priority = 2, capacity = 8, shared = [layout])]
    fn handle_event(c: handle_event::Context, event: Event) {
        c.shared.layout.event(event)
    }

    #[task(priority = 2, shared = [usb_dev, usb_class, layout])]
    fn tick_keyberon(mut c: tick_keyberon::Context) {
        let tick = c.shared.layout.tick();
        if c.shared.usb_dev.lock(|d| d.state()) != UsbDeviceState::Configured {
            return;
        }
        match tick {
            CustomEvent::Release(()) => bootloader(),
            _ => (),
        }
        let report: KbHidReport = c.shared.layout.keycodes().collect();
        if !c
            .shared
            .usb_class
            .lock(|k| k.device_mut().set_keyboard_report(report.clone()))
        {
            return;
        }
        while let Ok(0) = c.shared.usb_class.lock(|k| k.write(report.as_bytes())) {}
    }

    #[task(
        binds = TIM3,
        priority = 1,
        local = [matrix, debouncer, timer, transform, tx],
    )]
    fn tick(c: tick::Context) {
        c.local.timer.wait().ok();

        for event in c
            .local
            .debouncer
            .events(c.local.matrix.get().get())
            .map(c.local.transform)
        {
            for &b in &ser(event) {
                block!(c.local.tx.write(b)).get();
            }
            handle_event::spawn(event).unwrap();
        }
        tick_keyberon::spawn().unwrap();
    }
}

fn de(bytes: &[u8]) -> Result<Event, ()> {
    match *bytes {
        [b'P', i, j, b'\n'] => Ok(Event::Press(i, j)),
        [b'R', i, j, b'\n'] => Ok(Event::Release(i, j)),
        _ => Err(()),
    }
}
fn ser(e: Event) -> [u8; 4] {
    match e {
        Event::Press(i, j) => [b'P', i, j, b'\n'],
        Event::Release(i, j) => [b'R', i, j, b'\n'],
    }
}

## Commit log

2020-07-04 Import left pcb
    [left.kicad_pcb, left.sch]
2020-07-05 right advances
    [_saved_right.sch, left.kicad_pcb, left.sch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]
2020-07-06 right: placement + 3.3V
    [right.kicad_pcb]
2020-07-06 more trace
    [right.kicad_pcb]
2020-07-07 right: rows routed
    [right.kicad_pcb]
2020-07-07 Right routed
    [right.kicad_pcb]
2020-07-30 fix diode bug on right
    [_saved_right.sch, right.kicad_pcb, right.sch]
2020-07-30 right: small tweeks
    [right.kicad_pcb]
2020-07-30 right: silk
    [right.kicad_pcb]
2020-07-30 left: correct diode bug
    [left.kicad_pcb, left.sch]
2020-07-30 left: change switch footprint
    [left.kicad_pcb, left.sch]
2020-07-30 left: silk
    [left.kicad_pcb]
2020-07-30 big tracks for power
    [left.kicad_pcb]
2020-07-30 small tweaks
    [left.kicad_pcb, right.kicad_pcb]
2020-08-02 smaller text
    [left.kicad_pcb, right.kicad_pcb]
2020-08-02 custom switch footprint
    [left.kicad_pcb, left.sch, right.kicad_pcb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]
2020-08-02 gerber conf
    [left.kicad_pcb, right.kicad_pcb]
2020-08-02 order number placeholder for JLPCB
    [left.kicad_pcb, right.kicad_pcb]
2020-08-02 generated gerber for v0.1
    [left-B.Cu.gbl, left-B.Mask.gbs, left-B.SilkS.gbo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]
2020-08-18 Fix LDO
    [left.kicad_pcb, left.sch, right.kicad_pcb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]
2020-08-18 Fix diode orientation
    [left.kicad_pcb, left.sch, right.kicad_pcb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]
2020-08-18 update gerber changelog
2020-08-28 more functionnal firmware for serial communication (but still doesn't work)
    [main.rs]
2020-09-12 BOM corrections
2020-09-12 BOM typo cleaning
2020-09-12 better BOM
2020-09-25 Correct MCU package in BOM
2020-11-02 Plate, without extreme thumb key
    [plate.scad]
2020-11-03 complete plate
    [plate.scad]
2020-11-03 Corrected plates
    [plate.scad, plate_left.stl, plate_right.stl]
2020-11-03 Document the cad directory
2020-11-06 Comment the cad/plate.scad file
    [plate.scad]
2020-12-02 Corrections on the PCB
    [left-B.Cu.gbl, left-B.Mask.gbs, left-B.SilkS.gbo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]
2021-08-12 fat MX plate
    [fat_mx_plate.printing.scad, fat_mx_plate.stl, functions.scad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]
2021-08-12 cutting pattern
    [cutting_pattern.printing.scad, cutting_pattern.stl]
2021-08-13 Correction on cutting pattern files
    [cutting_pattern.printing.scad, cutting_pattern.stl]
2021-09-03 More parallel usb trace on left
    [left.kicad_pcb]
2021-12-26 Some try at STM assembly (clearly not yet ready)
    [left-B_Cu.gbl, left-B_Mask.gbs, left-B_SilkS.gbo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]
2022-01-13 Small changes for left manufactured SMT
    [left.sch, left_bom.csv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]
2024-05-30 fix goto bootloader for when reset inside bootloader
    [main.rs]
